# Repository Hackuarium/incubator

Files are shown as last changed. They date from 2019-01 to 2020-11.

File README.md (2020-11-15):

# Cheap and simple incubator

Can we do a simple incubator that is actually more advanced than the commercial one ?

The idea of this project is to create the hardware that allows to control a peltier
thermoelectric module in order to warm or cool down a closed space.

In order to make an incubator we want to use any polystyrene box, make a hole and
insert a module.

A smart control should allow precise control of the temperature not only to warm up
but also to cool down and to define a temperature program. Like that you could incubate
couple of culture plate at 37°C the Friday evening and program the incubator so 
that it cools down to 4°C after 24h.

Well this is still a work in progress. The PCB in done and functional. The fun starts now !

## Cloning the project

In order to clone it use:

git clone --recurse-submodules https://github.com/hackuarium/incubator

To update the submodules:

git submodule update --recursive --remote

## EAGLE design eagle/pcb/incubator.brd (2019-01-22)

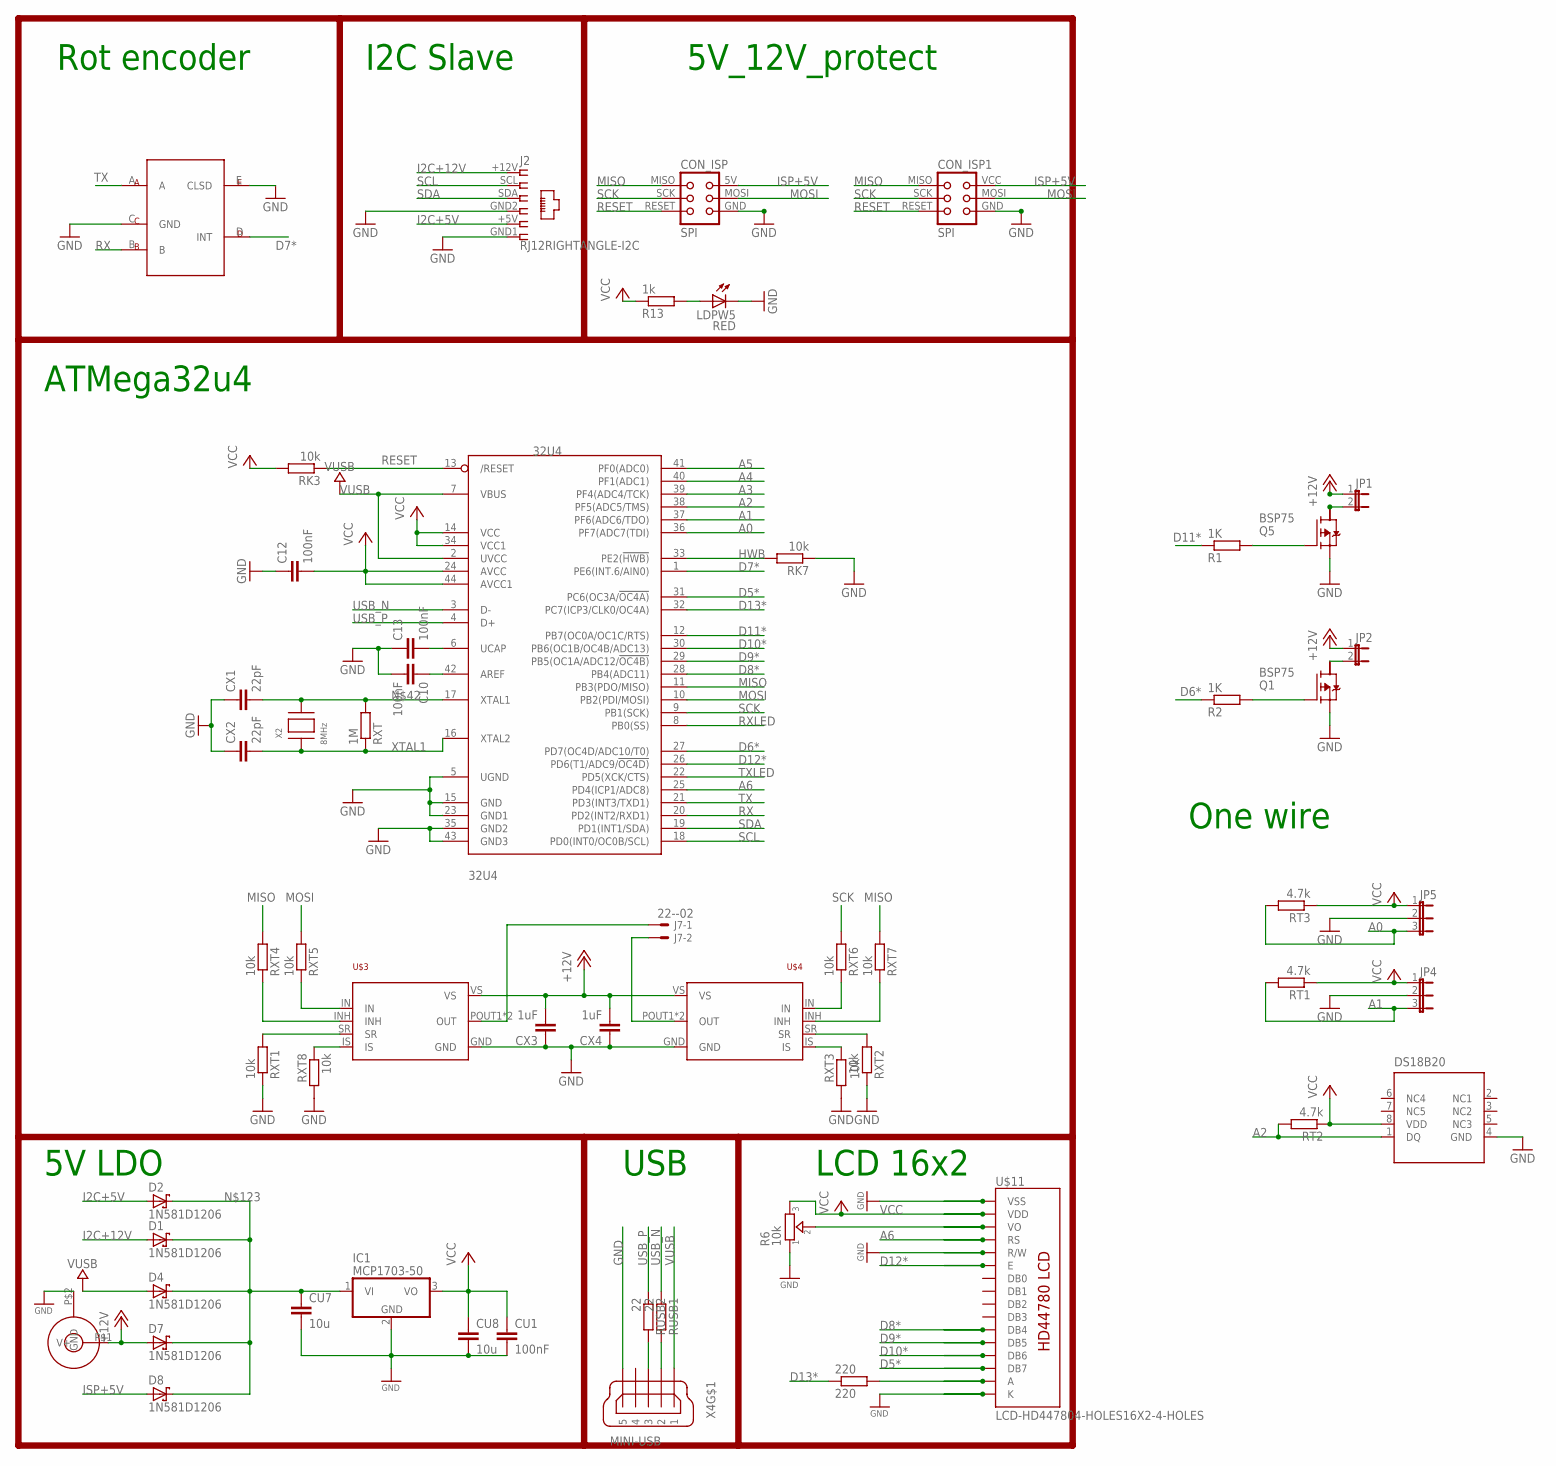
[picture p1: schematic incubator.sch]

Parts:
32U4: 32U4; TQFP44
220: 220; R0805
C10, C12, C13: 100nF; C0805
CON_ISP: SPI; TC2030-MCP-NL
CON_ISP1: SPI; TINYISP
CU1: 100nF; C0805
CU7, CU8: 10u; C0805
CX1, CX2: 22pF; C0805
CX3, CX4: 1uF; C0805
D1, D2, D4, D7, D8: 1N581D1206; LED-1206
IC1: MCP1703-50; SOT223
J2: RJ12RIGHTANGLE-I2C; RJ12-RIGHTANGLE-I2C
J7: 22--02; 2-PIN-5.08S
JP1, JP2: JUMPER-2PTH; 1X02
JP4, JP5: JP2E; JP2
LDPW5: RED; CHIP-LED0805
POWER: JACK_DC_BARREL; DC_BARREL
Q1, Q5: BSP75; PG-SOT-223
R1, R2: 1K; R0805
R6: 10k; TRIMMER_3362P
R13: 1k; R0805
RK3, RK7: 10k; M0805
RT1, RT2, RT3: 4.7k; R0805
RUSB1, RUSB2: 22; M0805
RXT: 1M; R0805
RXT1, RXT2, RXT3, RXT4, RXT5, RXT6, RXT7, RXT8: 10k; R0805
U$1: ROTARYENCODER
U$3, U$4: BTS7960; P-TO-263-7
U$5: DS18B20; MSOP8
U$11: LCD-HD447804-HOLES16X2-4-HOLES; LCD-16X2-4HOLES
X2: 8MHz; NX6035
X4: MINI-USB; 32005-201

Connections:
+12V: CX3.2, CX4.2, D7.A, JP1.1, JP2.1, POWER.P$1 (V+), U$3.VS, U$4.VS
A0: 32U4.36 (PF7(ADC7(TDI)), JP5.3, RT3.2
A1: 32U4.37 (PF6(ADC6/TDO)), JP4.3, RT1.2
A2: 32U4.38 (PF5(ADC5/TMS)), RT2.2, U$5.1 (DQ)
A3: 32U4.39 (PF4(ADC4/TCK))
A4: 32U4.40 (PF1(ADC1))
A5: 32U4.41 (PF0(ADC0))
A6: 32U4.25 (PD4(ICP1/ADC8)), U$11.4 (RS)
AREF: 32U4.42 (AREF), C10.1
D5*: 32U4.31 (PC6(OC3A/!OC4A)), U$11.14 (DB7)
D6*: 32U4.27 (PD7(OC4D/ADC10/T0)), R2.1
D7*: 32U4.1 (PE6(INT.6/AIN0)), U$1.D (INT)
D8*: 32U4.28 (PB4(ADC11)), U$11.11 (DB4)
D9*: 32U4.29 (PB5(OC1A/ADC12/!OC4B)), U$11.12 (DB5)
D10*: 32U4.30 (PB6(OC1B/OC4B/ADC13)), U$11.13 (DB6)
D11*: 32U4.12 (PB7(OC0A/OC1C/RTS)), R1.1
D12*: 32U4.26 (PD6(T1/ADC9/!OC4D)), U$11.6 (E)
D13*: 32U4.32 (PC7(ICP3/CLK0/OC4A)), 220.1
GND: 32U4.5 (UGND), 32U4.15 (GND), 32U4.23 (GND1), 32U4.35 (GND2), 32U4.43 (GND3), C10.2, C12.1, C13.1, CON_ISP.GND, CON_ISP1.GND, CU1.2, CU7.2, CU8.2, CX1.1, CX2.1, CX3.1, CX4.1, IC1.2 (GND), J2.GND1 (6), J2.GND2 (4), JP4.2, JP5.2, LDPW5.C, POWER.P$2 (GND), Q1.3 (S), Q5.3 (S), R6.1, RK7.1, RXT1.1, RXT2.1, RXT3.2, RXT8.2, U$1.C (GND), U$1.E (CLSD), U$3.GND, U$4.GND, U$5.4 (GND), U$11.1 (VSS), U$11.5 (R/W), U$11.16 (K), X4.5
HWB: 32U4.33 (PE2(!HWB)), RK7.2
I2C+5V: D2.A, J2.+5V (5)
I2C+12V: D1.A, J2.+12V (1)
ISP+5V: CON_ISP.5V (VCC), CON_ISP1.VCC, D8.A
MISO: 32U4.11 (PB3(PDO/MISO)), CON_ISP.MISO, CON_ISP1.MISO, RXT4.2, RXT7.2
MOSI: 32U4.10 (PB2(PDI/MOSI)), CON_ISP.MOSI, CON_ISP1.MOSI, RXT5.2
unnamed: 32U4.6 (UCAP), C13.2
unnamed: R6.2, U$11.3 (VO)
unnamed: RXT5.1, U$3.IN
unnamed: RXT6.1, U$4.IN
unnamed: RXT4.1, U$3.INH
unnamed: RXT7.1, U$4.INH
unnamed: RXT3.1, U$4.IS
unnamed: Q5.1 (G), R1.2
unnamed: RXT2.2, U$4.SR
unnamed: 220.2, U$11.15 (A)
unnamed: LDPW5.A, R13.2
unnamed: RXT1.2, U$3.SR
unnamed: RXT8.1, U$3.IS
unnamed: J7.1, U$3.POUT1 (OUT), U$3.POUT2 (OUT)
unnamed: Q1.1 (G), R2.2
unnamed: JP1.2, Q5.2 (D)
unnamed: J7.2, U$4.POUT1 (OUT), U$4.POUT2 (OUT)
unnamed: JP2.2, Q1.2 (D)
unnamed: 32U4.17 (XTAL1), CX1.2, RXT.2, X2.P$2
unnamed: CU7.1, D1.C, D2.C, D4.C, D7.C, D8.C, IC1.1 (VI)
RESET: 32U4.13 (/RESET), CON_ISP.RESET, CON_ISP1.RESET, RK3.1
RX: 32U4.20 (PD2(INT2/RXD1)), U$1.B
RXLED: 32U4.8 (PB0(SS))
SCK: 32U4.9 (PB1(SCK)), CON_ISP.SCK, CON_ISP1.SCK, RXT6.2
SCL: 32U4.18 (PD0(INT0/OC0B/SCL)), J2.SCL (2)
SDA: 32U4.19 (PD1(INT1/SDA)), J2.SDA (3)
TX: 32U4.21 (PD3(INT3/TXD1)), U$1.A
TXLED: 32U4.22 (PD5(XCK/CTS))
USBC_N: RUSB1.2, X4.2
USBC_P: RUSB2.2, X4.3
USB_N: 32U4.3 (D-), RUSB1.1
USB_P: 32U4.4 (D+), RUSB2.1
VCC: 32U4.14 (VCC), 32U4.24 (AVCC), 32U4.34 (VCC1), 32U4.44 (AVCC1), C12.2, CU1.1, CU8.1, IC1.3 (VO), JP4.1, JP5.1, R6.3, R13.1, RK3.2, RT1.1, RT2.1, RT3.1, U$5.8 (VDD), U$11.2 (VDD)
VUSB: 32U4.2 (UVCC), 32U4.7 (VBUS), D4.A, X4.1
XTAL1: 32U4.16 (XTAL2), CX2.2, RXT.1, X2.P$1

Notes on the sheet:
USB
5V_12V_protect
ATMega32u4
I2C Slave
LCD 16x2
Rot encoder
5V LDO
One wire

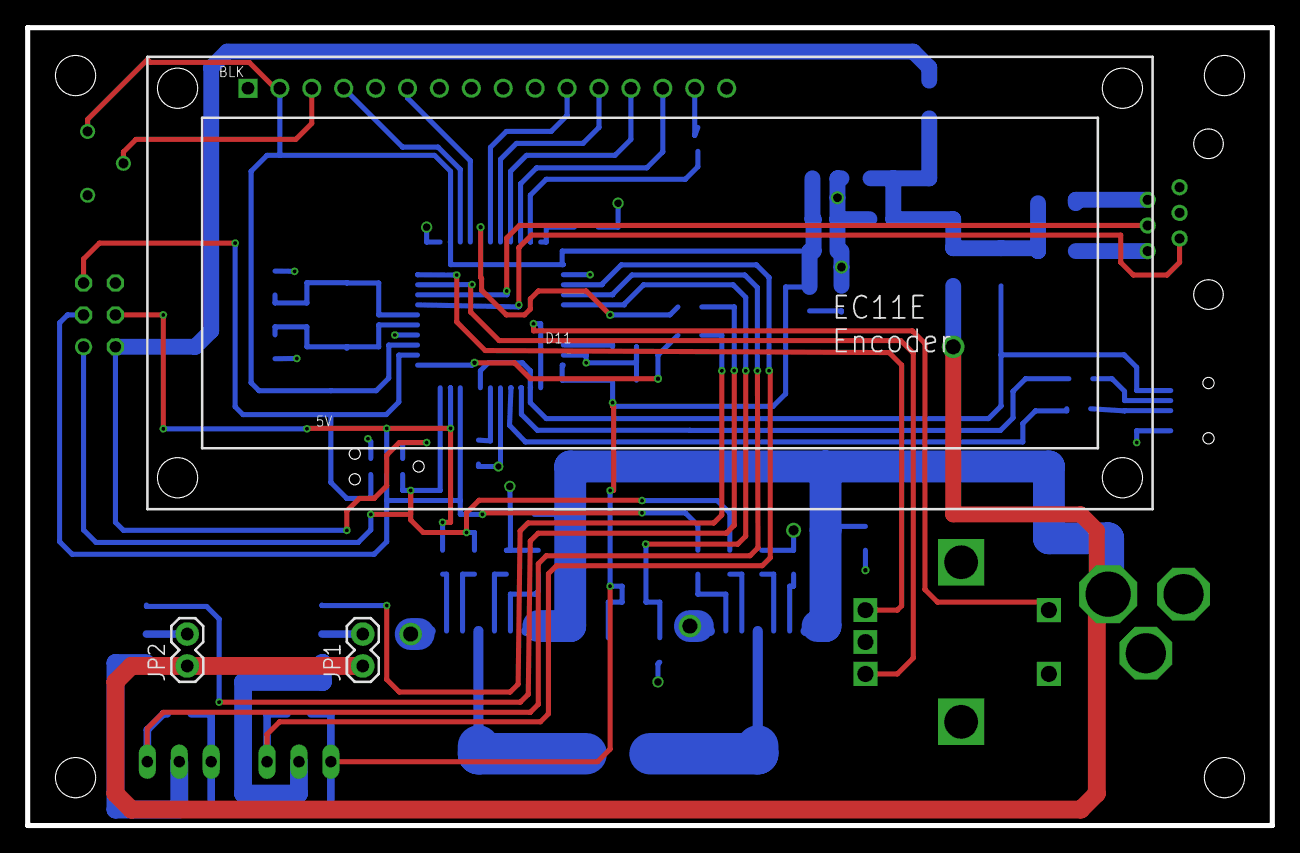
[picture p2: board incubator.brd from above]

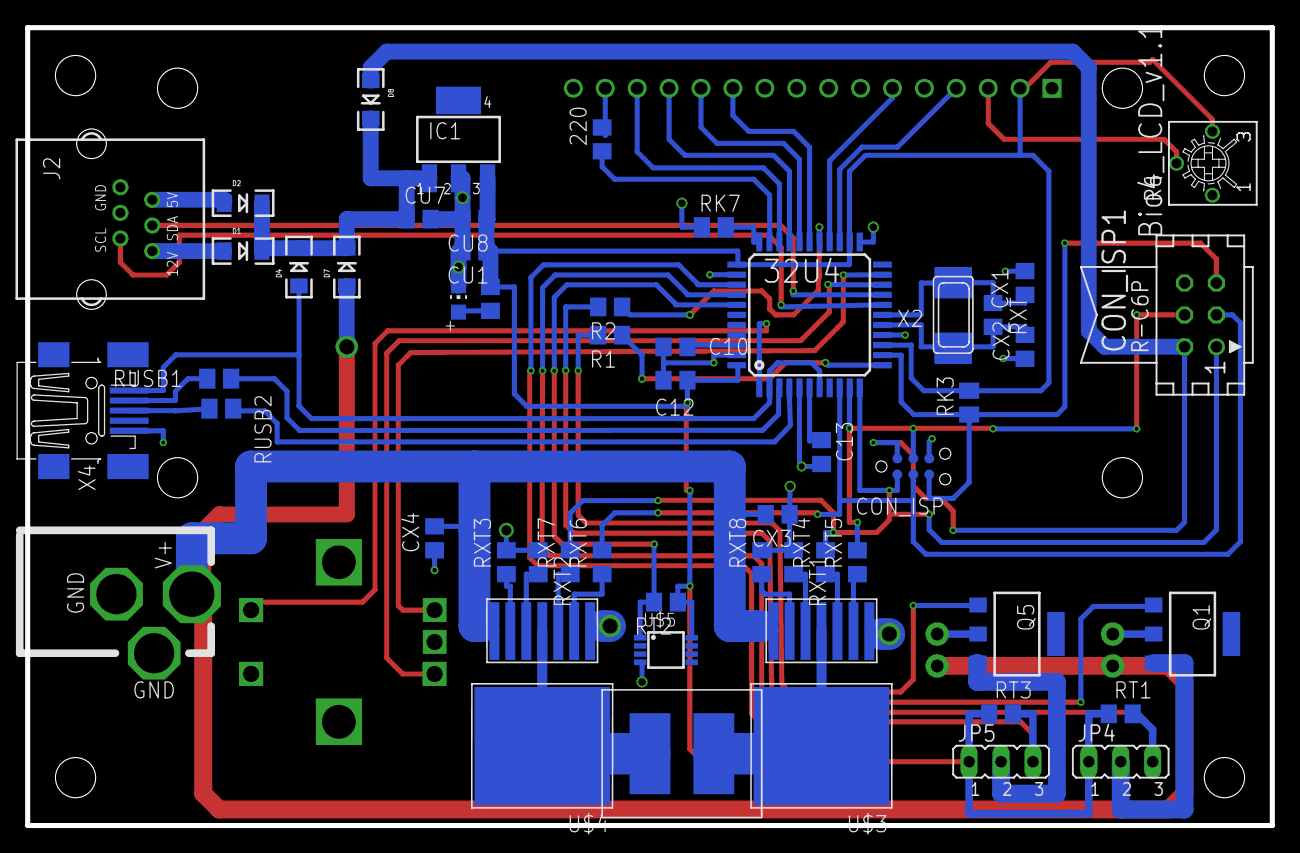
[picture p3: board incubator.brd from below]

Board: 4 copper layers, 99.1 x 63.5 mm, 57 parts (53 on the bottom side), 55 nets.

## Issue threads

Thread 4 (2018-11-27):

Rotary push button is wrongly connected

lpatiny, 2018-11-27:
Ground should be in the middle

Closed 2018-12-11.

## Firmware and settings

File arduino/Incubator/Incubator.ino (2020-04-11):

#define THR_SERIAL      1


#include "A_Parameters.h"

#define THR_EEPROM_LOGGER 1
#define NUMBER_PARAMETERS_TO_LOG 6  // defines the number of parameters to log
// allowed values: 1, 2, 3, 4, 6, 8, 10, 14
// 2 first entries in the log will be logID and secodns between
#define LOG_INTERVAL 900   // we log every 15 minutes
// we can store 60 entries in the log
#include "libino/hack.h"


#define TEMPERATURE_EXT_1    A0
#define TEMPERATURE_EXT_2    A1
#define TEMPERATURE_PCB      A2
#define FAN_EXTERNAL         6
#define FAN_INTERNAL         11

#define HBRIDGE_INH  MISO
#define HBRIDGE_IN1  SCK
#define HBRIDGE_IN2  MOSI


#define THR_ERROR 13 // define the pin to blink if there is an error




void setup() {

delay(500);
  
  setupParameters();
  checkParameters();
  nilSysBegin();
}

void loop() {}

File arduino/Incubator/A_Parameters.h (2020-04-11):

#define MAX_PARAM       26

#define PARAM_TEMP_EXT_1    0
#define PARAM_TEMP_EXT_2    1
#define PARAM_TEMP_TARGET   2
#define PARAM_HBRIDGE_PID   3

#define PARAM_FAN_EXTERNAL  4
#define PARAM_FAN_INTERNAL  5

#define PARAM_TEMP_PCB      8


#define PARAM_TEMP_TARGET_1  10
#define PARAM_TIME_1         11
#define PARAM_TEMP_TARGET_2  12
#define PARAM_TIME_2         13
#define PARAM_TEMP_TARGET_3  14
#define PARAM_TIME_3         15


#define PARAM_FLAGS           17
#define PARAM_FLAG_INVERT_ROTARY 0  // invert rotary direction

#define PARAM_CURRENT_TIME   20
#define PARAM_STATE          21 // current state

#define STATE_OFF        0
#define STATE_CONSTANT   1
#define STATE_PROGRAM    2

#define PARAM_MENU          22 // current menu

/******************
   FLAG DEFINITION
 ******************/
#define PARAM_ENABLED      23
#define FLAG_FAN_EXTERNAL_CONTROL     0
#define FLAG_FAN_INTERNAL_CONTROL     1
#define FLAG_PID_CONTROL              2

#define PARAM_ERROR        24
#define FLAG_TEMP_PCB_PROBE_ERROR        0   // pcb probe failed (one wire not answering)
#define FLAG_TEMP_EXT_1_PROBE_ERROR      1   // ext probe 1 failed (one wire not answering)
#define FLAG_TEMP_EXT_2_PROBE_ERROR      2   // ext probe 2 failed (one wire not answering)

#define FLAG_TEMP_PCB_RANGE_ERROR        3   // temperature of pcb is outside range
#define FLAG_TEMP_EXT_1_RANGE_ERROR      4   // temperature of liquid is outside range
#define FLAG_TEMP_EXT_2_RANGE_ERROR      5   // temperature of liquid is outside range
#define FLAG_TEMP_TARGET_RANGE_ERROR     6   // target temperature is outside range

#define PARAM_STATUS             25  // current status

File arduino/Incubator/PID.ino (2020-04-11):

#include "libino/PID/PID_v1.h"

#define PID_OUTPUT_LIMIT 255

void pid_ctrl();

double heatingRegInput;
double heatingRegOutput;
double heatingRegSetpoint;
PID heatingRegPID(&heatingRegInput, &heatingRegOutput, &heatingRegSetpoint, 1, 0.0002, 5, DIRECT);

NIL_WORKING_AREA(waThreadPID, 256);
NIL_THREAD(ThreadPID, arg) {

  heatingRegPID.SetOutputLimits(0, PID_OUTPUT_LIMIT);
  heatingRegPID.SetMode(AUTOMATIC);      //turn the PID on, cf. PID library
  heatingRegPID.SetSampleTime(950);      //set PID sampling time to 90ms

  pinMode(FAN_EXTERNAL, OUTPUT);
  pinMode(FAN_INTERNAL, OUTPUT);
  pinMode(HBRIDGE_IN1, OUTPUT);
  pinMode(HBRIDGE_IN2, OUTPUT);
  pinMode(HBRIDGE_INH, OUTPUT);


  while (true) {
    if (isError() || getParameter(PARAM_STATE) != STATE_CONSTANT) {
      digitalWrite(FAN_EXTERNAL, LOW);
      digitalWrite(FAN_INTERNAL, LOW);
      digitalWrite(HBRIDGE_INH, LOW);
    } else {
      if ( getParameterBit(PARAM_ENABLED, FLAG_FAN_EXTERNAL_CONTROL)) {
        analogWrite(FAN_EXTERNAL, getParameter(PARAM_FAN_EXTERNAL));
      } else {
        digitalWrite(FAN_EXTERNAL, LOW);
      }
      if ( getParameterBit(PARAM_ENABLED, FLAG_FAN_INTERNAL_CONTROL)) {
        analogWrite(FAN_INTERNAL, getParameter(PARAM_FAN_INTERNAL));
      } else {
        digitalWrite(FAN_INTERNAL, LOW);
      }



      if ( getParameterBit(PARAM_ENABLED, FLAG_PID_CONTROL)) {
        digitalWrite(HBRIDGE_INH, HIGH);

        heatingRegInput = (getParameter(PARAM_TEMP_EXT_1) + getParameter(PARAM_TEMP_EXT_2)) / 2;
        heatingRegSetpoint = getParameter(PARAM_TEMP_TARGET);
        heatingRegPID.Compute();    // the computation takes only 30ms!

        setParameter(PARAM_HBRIDGE_PID, heatingRegOutput);
        analogWrite(HBRIDGE_IN1, heatingRegOutput);
      } else {
        digitalWrite(HBRIDGE_INH, LOW);
      }
    }
    nilThdSleepMilliseconds(500);
  }
}

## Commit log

2017-07-08 First design thinking
    [fridge.brd, fridge.sch]
2017-08-09 routing in progress
    [fridge.brd, incubator.brd, incubator.sch]
2017-08-14 first version of the incubator
    [incubator.brd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]
2017-09-23 add test case and begin arduino program
    [incubator.brd]
2017-09-29 working on PID
2018-12-04 Library for new Rotary Encoder designed by Hans
2018-12-04 changed name to Rotary Encoder
2018-12-11 45 degree traces
    [incubator.brd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]
2018-12-11 version 1.1
    [incubator.brd, incubator.sch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]
2019-01-22 version 1.1.0
    [incubator.brd, incubator.sch]
2019-03-19 working on new arduino for version 1.1.0
2020-04-11 fix: fix manuy parameters bugs
    [A_Parameters.h, Incubator.ino, Init.ino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]

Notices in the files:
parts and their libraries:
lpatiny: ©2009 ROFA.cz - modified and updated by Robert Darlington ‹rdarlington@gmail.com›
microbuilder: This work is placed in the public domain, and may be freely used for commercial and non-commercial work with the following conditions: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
